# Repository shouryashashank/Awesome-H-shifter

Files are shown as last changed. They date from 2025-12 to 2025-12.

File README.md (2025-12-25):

# Awesome H-Shifter

A DIY 8-speed H-pattern shifter that converts a physical H-stick and switches into a USB gamepad for sim racing. The project uses a Arduino Pro Micro (ATmega32U4) and a single-digit 7-segment display to show the current gear, plus an ignition button that runs a loading animation.



---

## Features

- 8 forward positions (1–7) + Reverse (R) + Neutral
- Ignition push-button that triggers a loading animation and can disable gear outputs while pressed
- Exposes gears and ignition as joystick buttons via the Arduino Joystick library (native USB)
- Simple wiring based on a Arduino Pro Micro (or any compatible ATmega32U4 board)
- Single 7-segment display for gear/neutral/reverse feedback
- Eagle schematic included for reference (`awesome-H-shifter.sch`)

---

## Repository contents

- `awesome-H-shifter.sch` — Eagle schematic showing wiring of the Arduino Pro Micro, switches and 7-segment display
- `h-shifter-sketch.ino` — Arduino sketch for reading the shifter, updating the display and reporting joystick buttons
- `3d-print files` — contains the 3d print files for the shifter
- `README.md` — this file
- `LICENSE` — project license

---

## Hardware

Required parts (suggested):

- Arduino Pro Micro (ATmega32U4) or equivalent
- 5 momentary switches wired in an H pattern (left/right/extreme right/up/down)
- 1 ignition push button
- 1 single-digit 7-segment display (common-anode by default in the sketch)
- Wires, soldering tools, optional perfboard, enclosure and 3D-printed housing
- M3 nuts and bolts (20 mm and 30 mm or other similar lengths)
- 2 Rubber bands

See the included schematic for wiring and footprint details.

ps: DO NOT get Arduino uno or nano. we need a micro processor with HID capability. you can use any other micro processor that has HID support like esp32 or raspberry pie zero (will have to re write the code)

---

## Wiring / Pin mapping

The wiring in `h-shifter-sketch.ino` maps pins as follows (Pro Micro pin numbers):

- Shifter inputs (configured INPUT_PULLUP):
  - Pin 2 -> LEFT
  - Pin 3 -> RIGHT
  - Pin 4 -> RIGHTEXTREME
  - Pin 5 -> UP
  - Pin 6 -> DOWN
- Ignition button: Pin 21 (A3) — INPUT_PULLUP (active low)

7-segment segment pins (as defined in sketch):
- SEG_A: 7
- SEG_B: 8
- SEG_C: 9
- SEG_D: 10
- SEG_E: 16 (A2)
- SEG_F: 14 (A0)
- SEG_G: 18 (A4)

Joystick mapping (USB gamepad):
- Buttons 0..7 represent gears 1..8 (button index = gear-1)
- Button 8 (index 8) is ignition

---

## Software / Upload

1. Open `h-shifter-sketch.ino` in the Arduino IDE or PlatformIO.
2. Select the correct board (Pro Micro or other ATmega32U4 board) and the correct port.
3. Ensure a compatible Joystick library is available. The sketch uses the built-in Joystick support for 32U4 cores; if your core lacks it, install an appropriate Joystick library.
4. Compile and upload the sketch.
5. Test the device in your OS game controller settings or in a game — the board should enumerate as a USB gamepad with 9 buttons.

---

## Behavior summary

- With ignition NOT pressed: the shifter inputs determine the gear. Neutral is used when no direction is pressed.
- With ignition pressed: the sketch runs a spinning/loading animation on the 7-segment and gear outputs remain disabled (configurable).
- The sketch only sends changed button states to the host to minimize USB traffic.

---

## Customization

- To use a common-cathode display, set `IS_COMMON_CATHODE` in `h-shifter-sketch.ino` to `true` and adjust wiring if needed.
- Remap input or segment pins by editing the `#define` statements at the top of `h-shifter-sketch.ino`.
- Add debounce or filtering to the input reads if you experience noisy switches.
- Change joystick button count or behavior in the Joystick constructor if you add more inputs.

---

## Troubleshooting

- Device not enumerating: make sure you uploaded to an ATmega32U4-based board (native USB). Reflash bootloader if necessary.
- Segments appear inverted or incorrect: confirm whether the display is common-anode (default) or common-cathode and set `IS_COMMON_CATHODE` accordingly.
- Phantom gear changes: implement debouncing (software or hardware), add short delays after reads, or use capacitors / better switch contacts.
- Wrong pin numbers: double-check the Pro Micro pin labels (A0/A1/A2 etc. may be mapped to different digital numbers depending on core).

---

## Schematic and photos

- See `awesome-H-shifter.sch` for the full Eagle schematic.
- The repository includes photos of an example 3D-printed shifter housing and wiring for reference.






---

## 3D printing files

The `3d-print files/` folder contains printable and editable models:

- `8shifter-body-new-clamp.3mf` — shifter body with integrated clamp
- `shift light.step` — STEP model of the shift display; edit to add more buttons if needed

Notes:
- Use either the body-with-clamp file or a plain body `.stl` (if you have one); there is no need to print both.
- The clamp version of the body is slightly more complex to print and may not be feasible on some bedslinger printers. The other parts are straightforward.
- Additional STEP models and the full original design are available from the creator's page: https://github.com/akakikuumeri/Akaki-H-shifter
- If you use the original body design, print clamps from: https://makerworld.com/en/models/504560-g-clamp-deeper?from=search#profileId-420208

---

## Credits

- Original 3D model and design by Akaki Kuumeri: https://github.com/akakikuumeri/Akaki-H-shifter
    - Akaki Kuumeri GitHub: https://github.com/akakikuumeri
- Original build and showcase video by Akaki Kuumeri: https://www.youtube.com/watch?v=fTknGo8n0Co
    - Akaki Kuumeri YouTube channel: https://www.youtube.com/@akakikuumeri
- Detailed assembly video by S60Team: https://www.youtube.com/watch?v=xyWhzIESEnE
  - S60Team YouTube channel: https://www.youtube.com/@S60Team
- Clamp designer on MakerWorld: https://makerworld.com/en/@sweb3791
  - G-Clamp deeper model: https://makerworld.com/en/models/504560-g-clamp-deeper?from=search#profileId-420208

---

## Contributing

Contributions, issues and pull requests are welcome. When submitting changes, prefer small focused commits and document any pin or wiring changes.

---

## License

See the `LICENSE` file in this repository.

---

Enjoy building and racing!

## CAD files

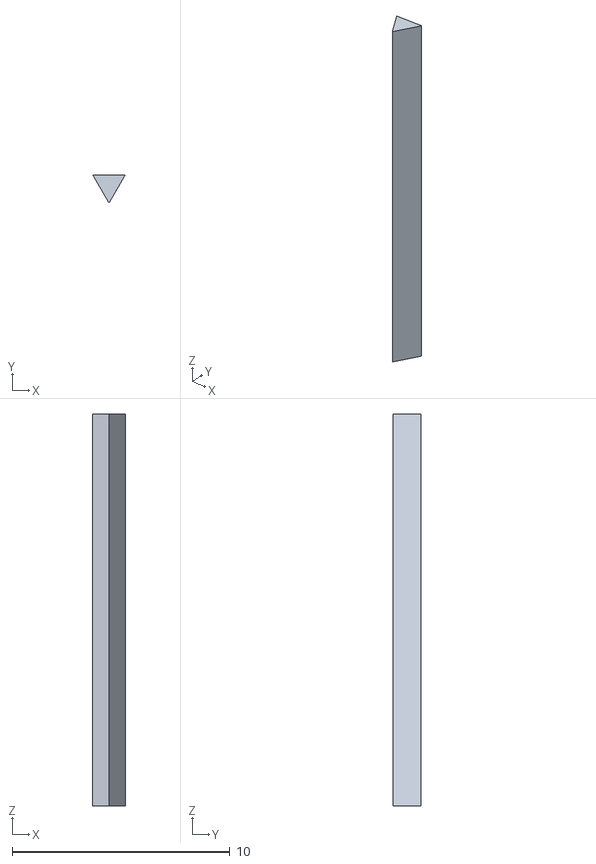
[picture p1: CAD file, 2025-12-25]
3d-print files/ROD_1.5.stl
1.50 x 1.30 x 18.0

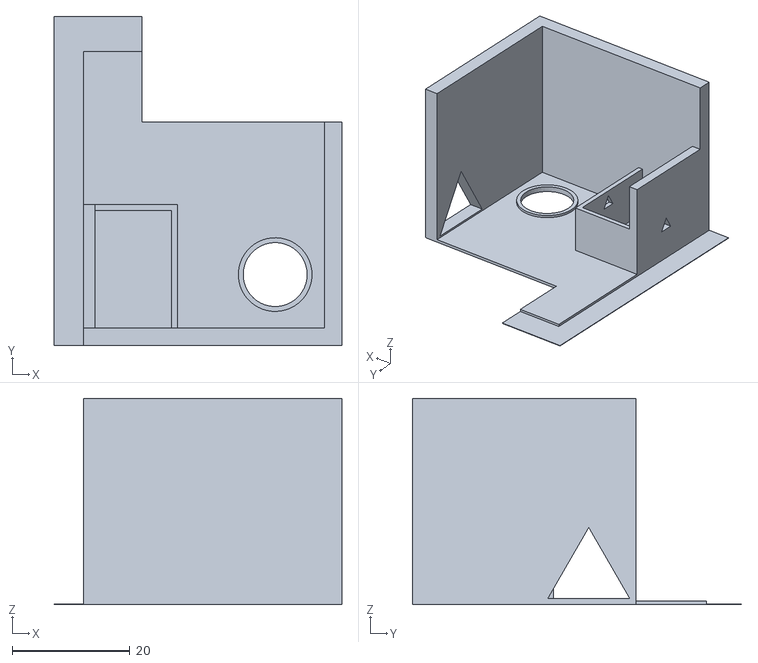
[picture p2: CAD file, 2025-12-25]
3d-print files/SHIFT_DISP_5.stl
49.0 x 56.0 x 35.1

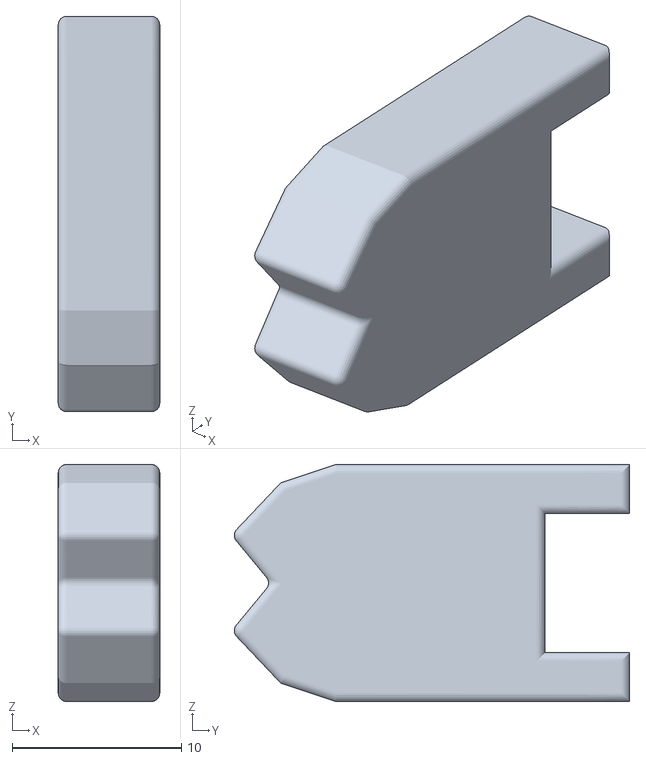
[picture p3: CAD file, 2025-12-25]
3d-print files/hinge_cam_-_glue_onto_hinge.stl
6.00 x 23.4 x 14.0

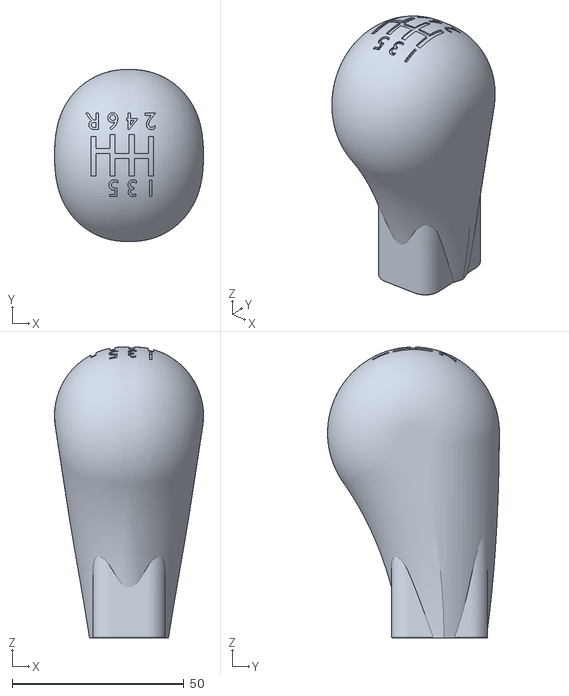
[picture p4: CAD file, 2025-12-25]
3d-print files/knob.stl
43.4 x 50.0 x 84.6

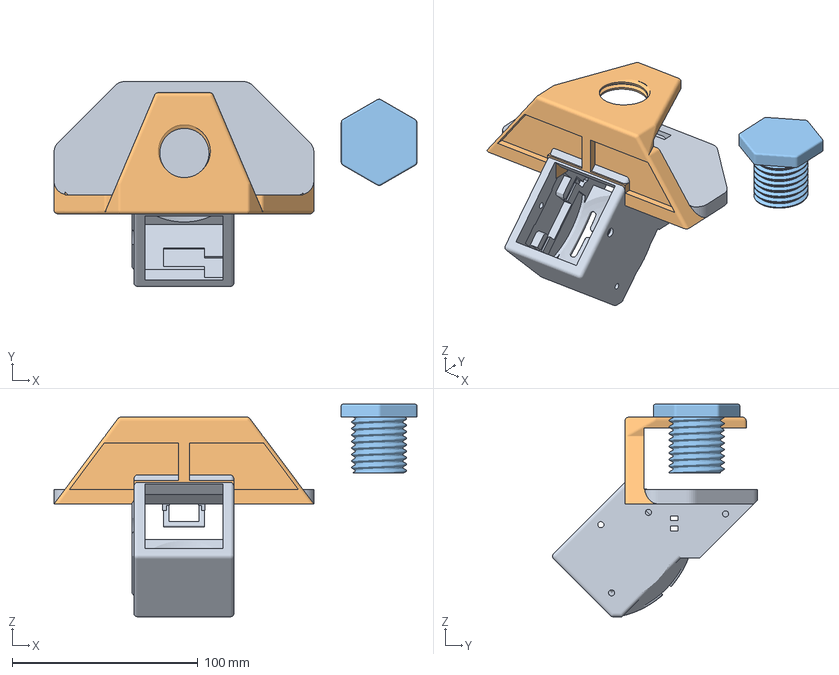
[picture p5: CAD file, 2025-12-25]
3d-print files/8shifter-body-new-clamp.3mf
195.5 x 110.4 x 114.6 mm
Body - Copy

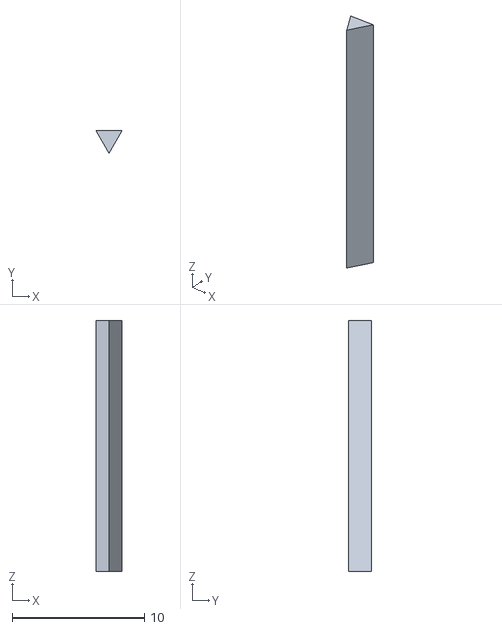
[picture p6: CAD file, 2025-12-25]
3d-print files/ROD_1.9.stl
1.98 x 1.71 x 19.0

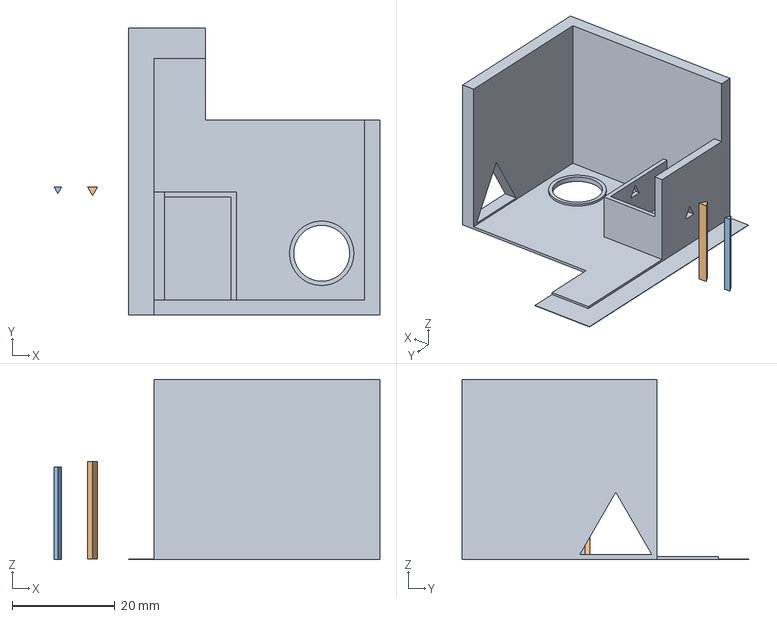
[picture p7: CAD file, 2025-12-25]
3d-print files/shift light.step
63.5 x 56.0 x 35.1 mm

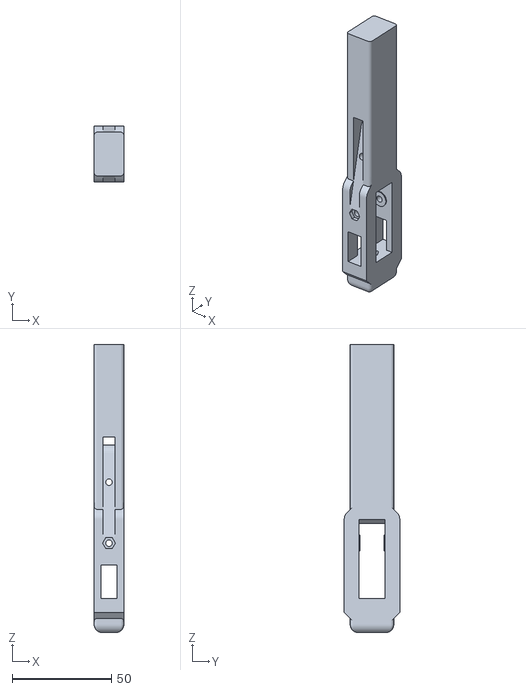
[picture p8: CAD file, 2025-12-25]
3d-print files/shaft.stl
15.0 x 28.0 x 145.0

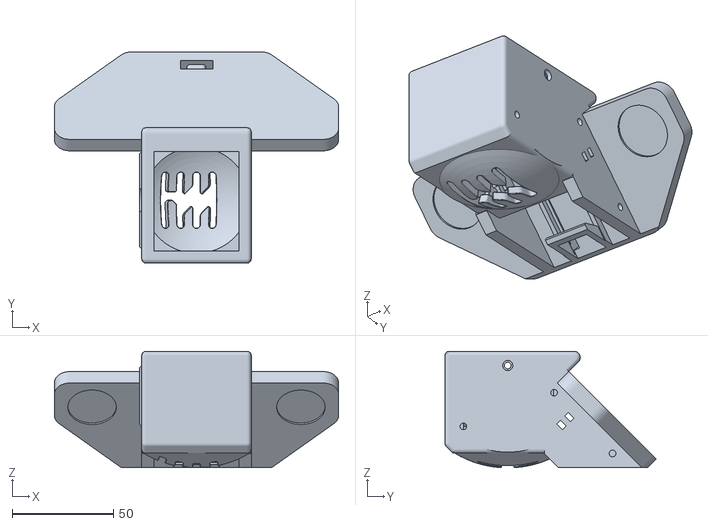
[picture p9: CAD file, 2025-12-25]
3d-print files/Body.stl
140.0 x 104.1 x 57.3

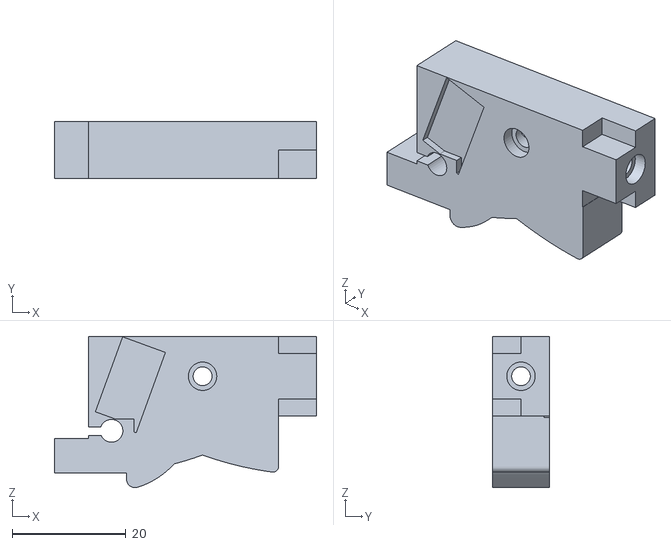
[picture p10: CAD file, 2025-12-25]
3d-print files/hinge.stl
46.0 x 10.0 x 26.6

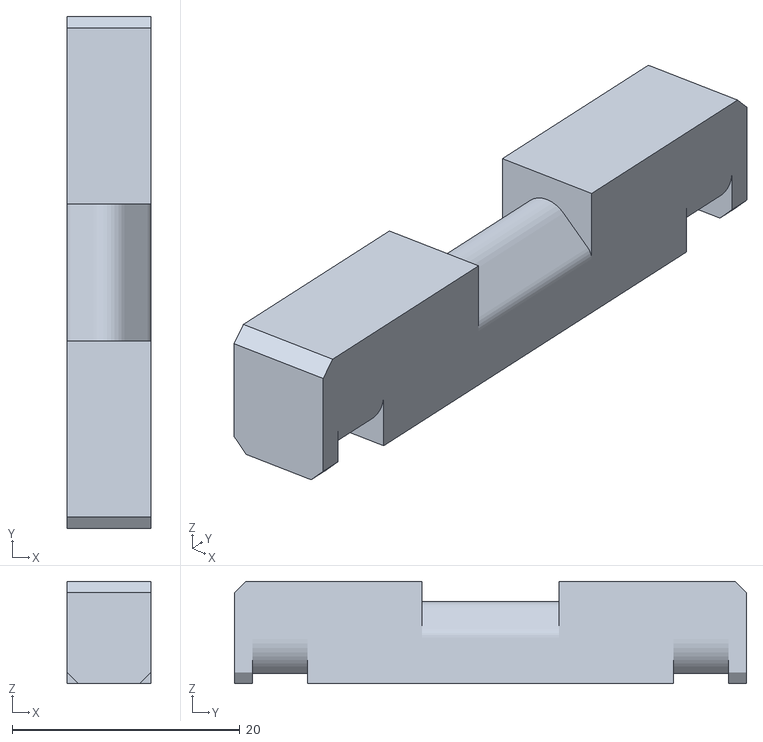
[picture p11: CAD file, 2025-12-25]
3d-print files/left_right_cam_slider.stl
7.40 x 45.0 x 9.00

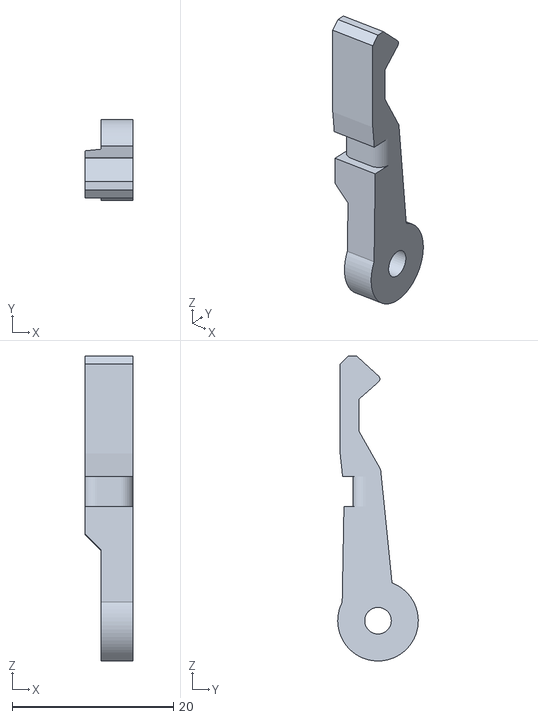
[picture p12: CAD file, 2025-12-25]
3d-print files/up_down_rachet.stl
6.00 x 10.00 x 37.8

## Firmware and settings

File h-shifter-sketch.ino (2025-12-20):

// 8 speed H shifter using 4 switches (plus neutral) - Updated with 7-Segment Display and 9th Ignition Button
#include <Joystick.h>

// --- INPUT PINS ---
// 2: X left
// 3: X right
// 4: X right extreme
// 5: X up
// 6: Y down
#define IGNITION_PIN 21 // New: Ignition Button on Pin 21 (A3)

#define LEFT 0
#define RIGHT 1
#define RIGHTEXTREME 3  // mistakenly soldered in wrong pin
#define UP 2
#define DOWN 4
#define IGNITION_INPUT_INDEX 5 // Index 5 in the input array

// The 9th button index on the joystick will be used for ignition
#define IGNITION_JOYSTICK_BUTTON 8 

// --- DISPLAY PINS (Common Anode assumed: LOW turns ON) ---
#define SEG_A 7
#define SEG_B 8
#define SEG_C 9
#define SEG_D 10
#define SEG_E 16 // A2
#define SEG_F 14 // A0
#define SEG_G 18 // A4

const int displayPins[] = {SEG_A, SEG_B, SEG_C, SEG_D, SEG_E, SEG_F, SEG_G};

// --- DISPLAY CONFIGURATION ---
// Set this constant to 'false' for Common Anode (LOW=ON).
// Set this constant to 'true' for Common Cathode (HIGH=ON).
const bool IS_COMMON_CATHODE = false; 

// Joystick Setup: INCREASED to 9 buttons (8 forward/reverse + 1 ignition)
Joystick_ Joystick(JOYSTICK_DEFAULT_REPORT_ID,JOYSTICK_TYPE_GAMEPAD,
  9, 0,                      // Button Count is now 9
  false, false, false,       // No X, Y, Z Axis
  false, false, false,       // No Rx, Ry, or Rz
  false, false,              // No rudder or throttle
  false, false, false);      // No accelerator, brake, or steering

// Last state of the buttons (9 buttons: Gear 1-7, Reverse, Ignition)
int lastButtonState[9] = {0,0,0,0,0,0,0,0,0};
int currentButtonState[9] = {0,0,0,0,0,0,0,0,0};
// input array has 6 elements (0-4 shifter, 5 ignition)
int input[6] = {0,0,0,0,0,0}; 
int gear = 0; // 0 is neutral. 1-7 are forward gears. 8 is reverse.

void setup() {
  // Initialize Shifter Input Pins (2-6)
  pinMode(2, INPUT_PULLUP);
  pinMode(3, INPUT_PULLUP);
  pinMode(4, INPUT_PULLUP);
  pinMode(5, INPUT_PULLUP);
  pinMode(6, INPUT_PULLUP);
  // Initialize Ignition Pin
  pinMode(IGNITION_PIN, INPUT_PULLUP);

  // Initialize Display Pins as OUTPUT
  for (int i = 0; i < 7; i++) {
    pinMode(displayPins[i], OUTPUT);
    // All segments OFF initially
    digitalWrite(displayPins[i], IS_COMMON_CATHODE ? LOW : HIGH); 
  }

  // Initialize Joystick Library
  Joystick.begin();
}

/**
 * Turns segments of the 7-segment display ON or OFF based on the desired character.
 * 0 = logically ON, 1 = logically OFF
 */
void updateDisplay(int currentGear) {
  // Digit patterns: {A, B, C, D, E, F, G} 
  // 1 = OFF, 0 = ON (LOGICALLY)

  int segments[7] = {1, 1, 1, 1, 1, 1, 1}; // Default to all OFF

  switch (currentGear) {
    case 1: segments[1]=0; segments[2]=0; break;
    case 2: segments[0]=0; segments[1]=0; segments[3]=0; segments[4]=0; segments[6]=0; break;
    case 3: segments[0]=0; segments[1]=0; segments[2]=0; segments[3]=0; segments[6]=0; break;
    case 4: segments[1]=0; segments[2]=0; segments[5]=0; segments[6]=0; break;
    case 5: segments[0]=0; segments[2]=0; segments[3]=0; segments[5]=0; segments[6]=0; break;
    case 6: segments[0]=0; segments[2]=0; segments[3]=0; segments[4]=0; segments[5]=0; segments[6]=0; break;
    case 7: segments[0]=0; segments[1]=0; segments[2]=0; break;
    case 8: // Display 'R' (Reverse)
      segments[4]=0; segments[6]=0; 
      break;
    case 0: // Display '-' (Neutral / Middle Segment)
    default:
      segments[6]=0; // Middle Segment G ON
      break;
  }

  // Write the state to the physical pins
  for (int i = 0; i < 7; i++) {
    // Apply display type logic
    if (IS_COMMON_CATHODE) {
        digitalWrite(displayPins[i], !segments[i]); // CC: 1=ON
    } else {
        digitalWrite(displayPins[i], segments[i]); // CA: 0=ON
    }
  }
}

/**
 * Creates a "loading" or spinning animation by sequentially lighting segments.
 */
void animateLoading() {
  // Static variables maintain their value between calls
  static const long interval = 100; // Time per segment (100ms)
  static long previousMillis = 0;
  static int segmentIndex = 0;
  
  // Segments to light up sequentially (A, B, C, D, E, F)
  // This creates a clockwise spinning effect
  const int loadingSegments[] = {SEG_A, SEG_B, SEG_C, SEG_D, SEG_E, SEG_F};
  const int loadingLength = 6;

  if (millis() - previousMillis >= interval) {
    previousMillis = millis();

    // 1. Turn off all segments first
    for (int i = 0; i < 7; i++) {
        // OFF logic: HIGH for CA (false), LOW for CC (true)
        digitalWrite(displayPins[i], IS_COMMON_CATHODE ? LOW : HIGH);
    }
    
    // 2. Turn on the current segment
    int pinToWrite = loadingSegments[segmentIndex];
    // ON logic: LOW for CA (false), HIGH for CC (true)
    digitalWrite(pinToWrite, IS_COMMON_CATHODE ? HIGH : LOW);

    // 3. Move to the next segment
    segmentIndex = (segmentIndex + 1) % loadingLength;
  }
}

void loop() {
  // Read the 5 shifter inputs (pins 2-6, indices 0-4)
  for (int index = 0; index < 5; index++) {
    input[index] = !digitalRead(index + 2);
  }
  // Read the Ignition Input (pin 19, index 5)
  input[IGNITION_INPUT_INDEX] = !digitalRead(IGNITION_PIN);
  bool ignitionPressed = input[IGNITION_INPUT_INDEX];
  
  // --- GEAR LOGIC ---
  // Only detect gear if ignition is OFF (optional, but prevents phantom gear changes during startup)
  if (!ignitionPressed) {
    gear = 0; // Default to neutral

    if (input[UP]) { //if stick is up
      if (input[LEFT]) { gear = 1; } 
      else if (input[RIGHT]) {
        if (input[RIGHTEXTREME]) { gear = 7; } 
        else { gear = 5; }
      } else { gear = 3; }
    } else if (input[DOWN]) {
      if (input[LEFT]) { gear = 2; } 
      else if (input[RIGHT]) {
        if (input[RIGHTEXTREME]) { gear = 8; } // Gear 8 is Reverse (R)
        else { gear = 6; }
      } else { gear = 4; }
    } 
  } else {
    // If ignition is pressed, keep gear at 0 (or whatever state is desired while starting)
    gear = 0;
  }
  
  // --- JOYSTICK BUTTONS UPDATE ---
  
  // 1. Reset all gear buttons (0-7)
  for (int i = 0; i < 8; i++) {
    currentButtonState[i] = 0;
  }
  
  // 2. Set the current gear button (0-7) if a gear is engaged
  if (gear >= 1 && gear <= 8) {
    currentButtonState[gear-1] = 1; 
  }

  // 3. Set the ignition button (index 8)
  currentButtonState[IGNITION_JOYSTICK_BUTTON] = ignitionPressed;
  
  // Send out button commands for all 9 buttons (0-8)
  for (int index = 0; index < 9; index++) {
    if (currentButtonState[index] != lastButtonState[index]) {
      Joystick.setButton(index, currentButtonState[index]);
      lastButtonState[index] = currentButtonState[index];
    }
  }

  // --- DISPLAY UPDATE ---
  if (ignitionPressed) {
    animateLoading(); // Run animation if ignition button is pressed
  } else {
    updateDisplay(gear); // Display current gear/neutral
  }

  delay(10);
}

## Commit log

2025-12-25 Add 3D print files and update README
    Added multiple new 3D model files (.stl, .3mf, .step) for the 8shifter project, including body, rods, hinge, knob, and related components. Updated README.md to reflect these additions.
    [8shifter-body-new-clamp.3mf, Body.stl, ROD_1.5.stl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]
2025-12-25 Add section for 3D printing files to README
    Added documentation about available 3D printing files, including descriptions of included models, usage notes, and links to original designs and additional resources.
2025-12-25 Update README for switch configuration and print notes
    Clarifies the required switch configuration to 5 momentary switches for the H pattern and refines the note about the clamp version of the body for 3D printing.
2025-12-25 Add images to README for 3D-printed shifter
    Added images of example 3D-printed shifter housing and wiring.
2025-12-25 Add resistor library and R1 part to schematic
    Integrated the 'Resistor' library with multiple resistor packages and symbols, and added a new resistor part R1 (300 Ω, 0402 package) to the schematic.
    [awsome-H-shifter.sch]
2025-12-25 Add credits section to README
    A new 'Credits' section was added to acknowledge original designers, video creators, and clamp contributors, with relevant links for reference.
2025-12-25 Fix schematic filename typo and update references
    Renamed 'awsome-H-shifter.sch' to 'awesome-H-shifter.sch' and updated all references in README.md to match the corrected filename. Also added a note in the README about required microcontrollers with HID support and included a 3D print files directory entry.
    [awesome-H-shifter.sch]
